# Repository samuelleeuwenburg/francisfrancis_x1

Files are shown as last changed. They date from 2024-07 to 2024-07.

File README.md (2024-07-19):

# FrancisFrancis X1

## Building the binary

Create a build folder, run cmake with your wifi info and build the project
```
$ mkdir firmware/build && cd firmware/build
$ cmake .. -DWIFI_SSID="network_name" -DWIFI_PASSWORD="password"
$ make -j4
```

## Running

Run openocd in the firmware folder
```
$ (sudo) openocd
```

Then use gdb to load the code
```
$ arm-none-eabi-gdb -q -x openocd.gdb build/francisfrancisx1.elf 
```

## Livebook

To run the notebook without installing Livebook you can use docker
```
$ docker run -p 8080:8080 -p 8081:8081 --pull always -u $(id -u):$(id -g) -v $(pwd):/data ghcr.io/livebook-dev/livebook
```

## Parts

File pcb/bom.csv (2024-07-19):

Reference | Qty | MPN
C1 | 1 | C0805X104K5RAC
C2 | 1 | C0805Y103K5RACTU
D1 | 1 | 150080AS75000
F1 | 1 | 0031.8201.G
FB1,FB2 | 2 | 742792037
J1,SW1 | 2 | 1725656
J2,J3 | 2 | 1715721
PS1 | 1 | IRM-02-3.3
Q1 | 1 | 2N7002HR
R1 | 1 | RT0805FRE132K2L
R2,R5 | 2 | RT0805FRE1010KL
R3 | 1 | RT0805FRE07270RL
R4 | 1 | RT0805FRE07390RL
U1 | 1 | MAX31855KASA+T
U2 | 1 | CPC40055ST
U3 | 1 | SC0918

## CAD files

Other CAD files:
cad/enclosure.blend

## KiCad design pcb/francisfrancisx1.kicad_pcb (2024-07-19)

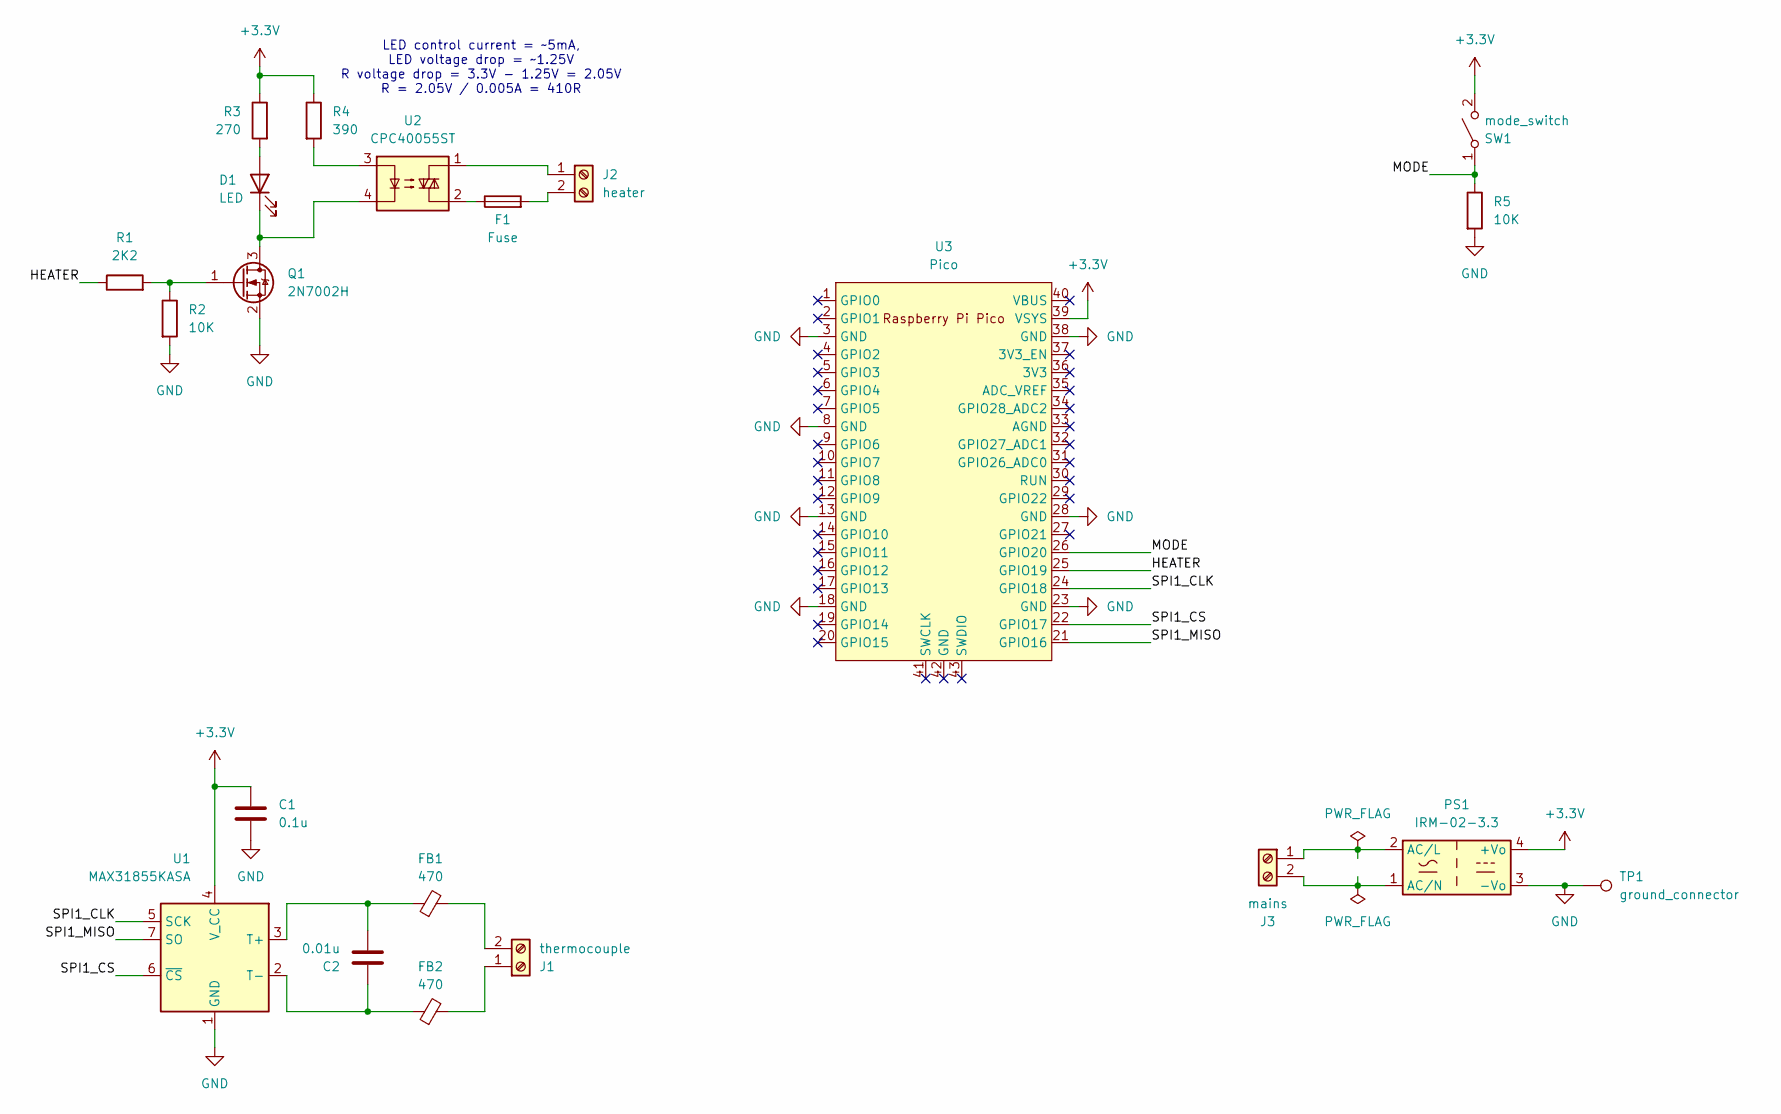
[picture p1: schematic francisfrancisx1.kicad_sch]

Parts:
C1: 0.1u; C_0805_2012Metric; MPN C0805X104K5RAC
C2: 0.01u; C_0805_2012Metric; MPN C0805Y103K5RACTU
D1: LED; LED_0805_2012Metric; MPN 150080AS75000
F1: Fuse; Fuseholder_Cylinder-5x20mm_Schurter_0031_8201_Horizontal_Op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; MPN 0031.8201.G
FB1, FB2: 470; R_0805_2012Metric; MPN 742792037
J1: thermocouple; TerminalBlock_Phoenix_MPT-0,5-2-2.54_1x02_P2.54mm_Horizontal; MPN 1725656
J2: heater; TerminalBlock_Phoenix_MKDS-1,5-2-5.08_1x02_P5.08mm_Horizont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; MPN 1715721
J3: mains; TerminalBlock_Phoenix_MKDS-1,5-2-5.08_1x02_P5.08mm_Horizont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; MPN 1715721
PS1: IRM-02-3.3; Converter_ACDC_MeanWell_IRM-02-xx_THT; MPN IRM-02-3.3
Q1: 2N7002H; SOT-23; MPN 2N7002HR
R1: 2K2; R_0805_2012Metric; MPN RT0805FRE132K2L
R2, R5: 10K; R_0805_2012Metric; MPN RT0805FRE1010KL
R3: 270; R_0805_2012Metric; MPN RT0805FRE07270RL
R4: 390; R_0805_2012Metric; MPN RT0805FRE07390RL
SW1: mode_switch; TerminalBlock_Phoenix_MPT-0,5-2-2.54_1x02_P2.54mm_Horizontal; MPN 1725656
TP1: ground_connector; MountingHole_2.2mm_M2_ISO7380_Pad
U1: MAX31855KASA; SOIC-8_3.9x4.9mm_P1.27mm; MPN MAX31855KASA+T
U2: CPC40055ST; MPN CPC40055ST
U3: Pico; RPi_Pico_SMD_TH; MPN SC0918

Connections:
+3.3V: C1.1, PS1.4 (+Vo), R3.1, R4.1, SW1.2 (B), U1.4 (V_CC), U3.39 (VSYS)
/HEATER: R1.1, U3.25 (GPIO19)
/MODE: R5.1, SW1.1 (A), U3.26 (GPIO20)
/SPI1_CLK: U1.5 (SCK), U3.24 (GPIO18)
/SPI1_CS: U1.6 (~CS), U3.22 (GPIO17)
/SPI1_MISO: U1.7 (SO), U3.21 (GPIO16)
GND: C1.2, PS1.3 (-Vo), Q1.2 (S), R2.2, R5.2, TP1.1, U1.1 (GND), U3.3 (GND), U3.8 (GND), U3.13 (GND), U3.18 (GND), U3.23 (GND), U3.28 (GND), U3.38 (GND)
unnamed: D1.2 (A), R3.2
unnamed: D1.1 (K), Q1.3 (D), U2.4
unnamed: F1.1, U2.2
unnamed: FB2.2, J1.1
unnamed: FB1.2, J1.2
unnamed: J2.1, U2.1
unnamed: F1.2, J2.2
unnamed: J3.1, PS1.2 (AC/L)
unnamed: J3.2, PS1.1 (AC/N)
unnamed: Q1.1 (G), R1.2, R2.1
unnamed: R4.2, U2.3
unnamed: C2.2, FB1.1, U1.3 (T+)
unnamed: C2.1, FB2.1, U1.2 (T-)

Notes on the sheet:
LED control current = ~5mA, LED voltage drop = ~1.25V R voltage drop = 3.3V - 1.25V = 2.05V R = 2.05V / 0.005A = 410R

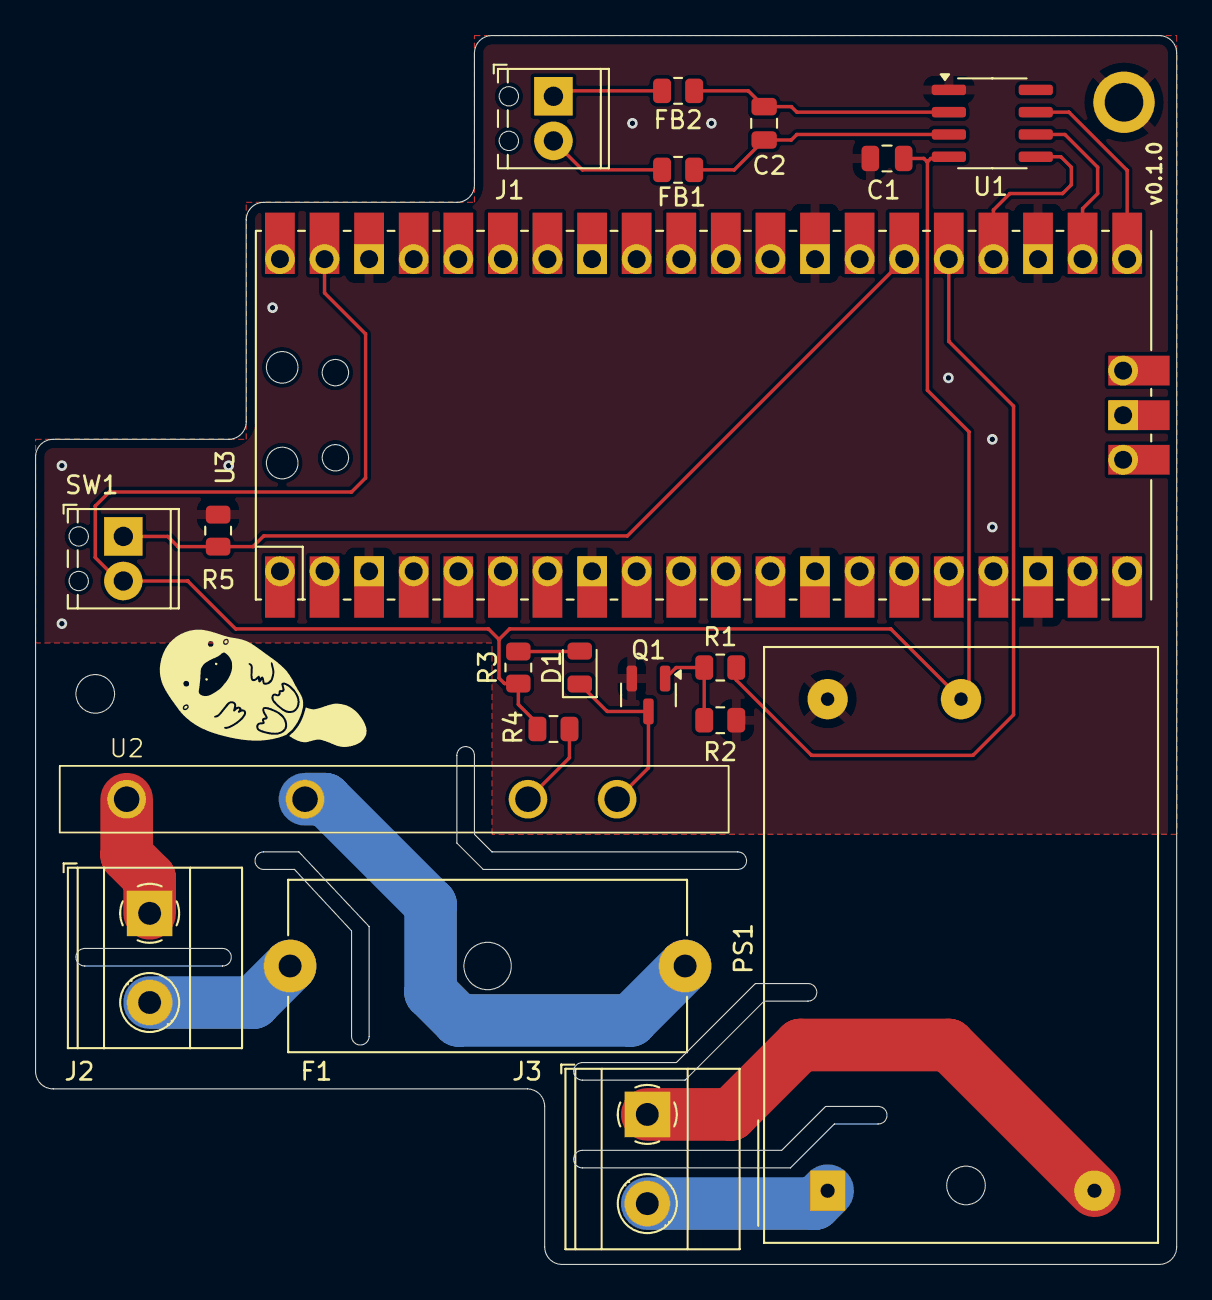
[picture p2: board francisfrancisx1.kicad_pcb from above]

Board: 2 copper layers, 65.0 x 70.0 mm, 21 parts (0 on the bottom side), 20 nets.

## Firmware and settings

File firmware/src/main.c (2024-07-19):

#include <string.h>
#include <stdio.h>
#include <stdlib.h>
#include "pico/stdlib.h"

#include "max31855.h"
#include "heater.h"
#include "server.h"

int main() {
    stdio_init_all();
    server_init();

    max31855 thermocouple = max31855_new();
    heater heater = heater_new();
    server_state state = {
        .heater = &heater,
        .thermocouple = &thermocouple,
    };

    max31855_init(&thermocouple);
    heater_init(&heater);

    server_setup(&state);

    for (;;) {
        sleep_ms(500);

	server_try_connect();
        server_poll();

        max31855_read(&thermocouple);

	if (thermocouple.errors > 0) {
	  heater_set_duty_cycle(&heater, 0.0);
	  continue;
	}

        heater_read_mode(&heater);
        heater_process(&heater, thermocouple.temperature);
    }

    server_deinit();

    return 0;
}

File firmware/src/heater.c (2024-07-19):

#include "pico/stdlib.h"
#include "hardware/pio.h"
#include "hardware/clocks.h"
#include "heater.h"
#include "pwm.pio.h"

#define ESPRESSO_TEMP 93.0
#define STEAM_TEMP 130.0

// GPIO
#define HEATER_CONTROL_PIN 19
#define HEATER_MODE_PIN 20

// PIO
#define CLOCK_DIVIDER 512.0
#define MAX_PWM_VALUE 0xffff

heater heater_new() {
    pid espresso_pid = pid_new(0.0, 100.0);
    espresso_pid.kp = 3.2;
    espresso_pid.ki = 0.002;
    espresso_pid.setpoint = ESPRESSO_TEMP;

    pid steamer_pid = pid_new(0.0, 100.0);
    steamer_pid.kp = 3.8;
    steamer_pid.ki = 0.002;
    steamer_pid.setpoint = STEAM_TEMP;

    heater h = {
        .espresso_pid = espresso_pid,
        .steamer_pid = steamer_pid,
        .duty_cycle = 0.0,
        .mode = Espresso,
        .pio = pio0,
        .pio_sm = pio_claim_unused_sm(pio0, true),
    };

    return h;
}


static void update_duty_cycle(heater *h) {
    // Convert percentile duty cycle to 16 bit value
    int level = (h->duty_cycle / 100.0) * MAX_PWM_VALUE;
    // pio_sm_put_blocking(h->pio, h->pio_sm, level);
    pio_sm_put(h->pio, h->pio_sm, level);
}

void heater_init(heater *h) {
    // Mode input
    gpio_init(HEATER_MODE_PIN);
    gpio_set_dir(HEATER_MODE_PIN, GPIO_IN);

    // Init PWM PIO program
    uint offset = pio_add_program(h->pio, &pwm_program);
    pwm_program_init(h->pio, h->pio_sm, offset, HEATER_CONTROL_PIN);

    // Setup total cycle duration
    pio_sm_set_enabled(h->pio, h->pio_sm, false);
    pio_sm_put_blocking(h->pio, h->pio_sm, (1u << 16) - 1);
    pio_sm_exec(h->pio, h->pio_sm, pio_encode_pull(false, false));
    pio_sm_exec(h->pio, h->pio_sm, pio_encode_out(pio_isr, 32));
    pio_sm_set_clkdiv(h->pio, h->pio_sm, CLOCK_DIVIDER);
    pio_sm_set_enabled(h->pio, h->pio_sm, true);
}

pid *heater_active_pid(heater *h) {
  if (h->mode == Espresso) {
    return &h->espresso_pid;
  } else {
    return &h->steamer_pid;
  }
}

void heater_read_mode(heater *h) {
    mode new_mode = gpio_get(HEATER_MODE_PIN);

    // If the mode changed, reset the pids and update the mode
    if (new_mode != h->mode) {
        pid_reset(&h->espresso_pid);
        pid_reset(&h->steamer_pid);
	h->mode = new_mode;
    }
}

void heater_set_duty_cycle(heater *h, float duty_cycle) {
    h->duty_cycle = duty_cycle;
    update_duty_cycle(h);
}

void heater_process(heater *h, float temperature) {
    pid *pid = heater_active_pid(h);
    float duty_cycle = pid_process(pid, temperature);
    heater_set_duty_cycle(h, duty_cycle);
}
